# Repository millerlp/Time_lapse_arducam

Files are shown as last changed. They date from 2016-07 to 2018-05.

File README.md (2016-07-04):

# Timelapse_ArduCam

This repository contains Arduino code and Eagle design files for a circuit board to interface
with an ArduCam camera module to generate timelapse images. The device will sleep until a 
user defined interval (some number of seconds) is reached, then it will boot up the 
ArduCam module, take one picture, and write it to the SD card before returning to sleep. The
ArduCam module consumes > 100mA while idling, so the AVR microcontroller uses a transistor to
cut off all power to the ArduCam, and puts itself to sleep as well. During sleep intervals the
average overall current draw of the entire device is < 1mA. During an image capture and save 
routine (approx 5-6 seconds), power draw is around 130mA. 

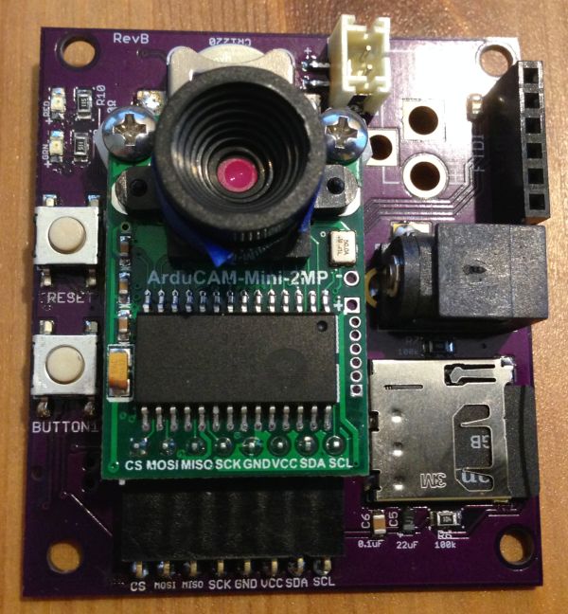
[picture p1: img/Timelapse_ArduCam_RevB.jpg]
Image of circuit board


The price for parts and the PCB boards should come out to $75, including the $30 cost of 
of the ArduCam OV2640 2 megapixel camera module
[Amazon link to camera module,](https://www.amazon.com/Arducam-Module-Megapixels-Arduino-Mega2560/dp/B012UXNDOY)
(note that the 5 megapixel version ought to work on this board as well) and the $22 cost to get 3 copies of the circuit board made by OshPark.com
[direct link to this board on Osh Park](https://oshpark.com/shared_projects/j0asS2vJ)

Features:
* Images are stored on a micro SD card.
* Timekeeping is accomplished with a DS3231 real time clock chip and backup battery.
* Power is provided by batteries through one of the available power plugs, either a 2.1mm barrel
connector or JST PH series plug (similar to that used on many Lithium battery packs). A 3.3V 
low dropout voltage regulator is included. I typically use 4 AA batteries to power the unit.
* A reset button and a trigger button are included, and can be mounted on either top or bottom 
of the board. 
* Indicator LEDs may also be mounted on the top or bottom of the board. 
* A FTDI header allows reprogramming of the AVR atmega328P microcontroller.
* A standard ICSP 2x3 header is available for burning a bootloader to the AVR. Alternatively, 
a Tag-Connect TC2030 footprint is available for ICSP functions as well. 

Necessary libraries:
* Arducam: https://github.com/ArduCAM/Arduino
* SdFat: https://github.com/greiman/SdFat
* RTClib: https://github.com/millerlp/RTClib

Written under Arduino 1.6.6

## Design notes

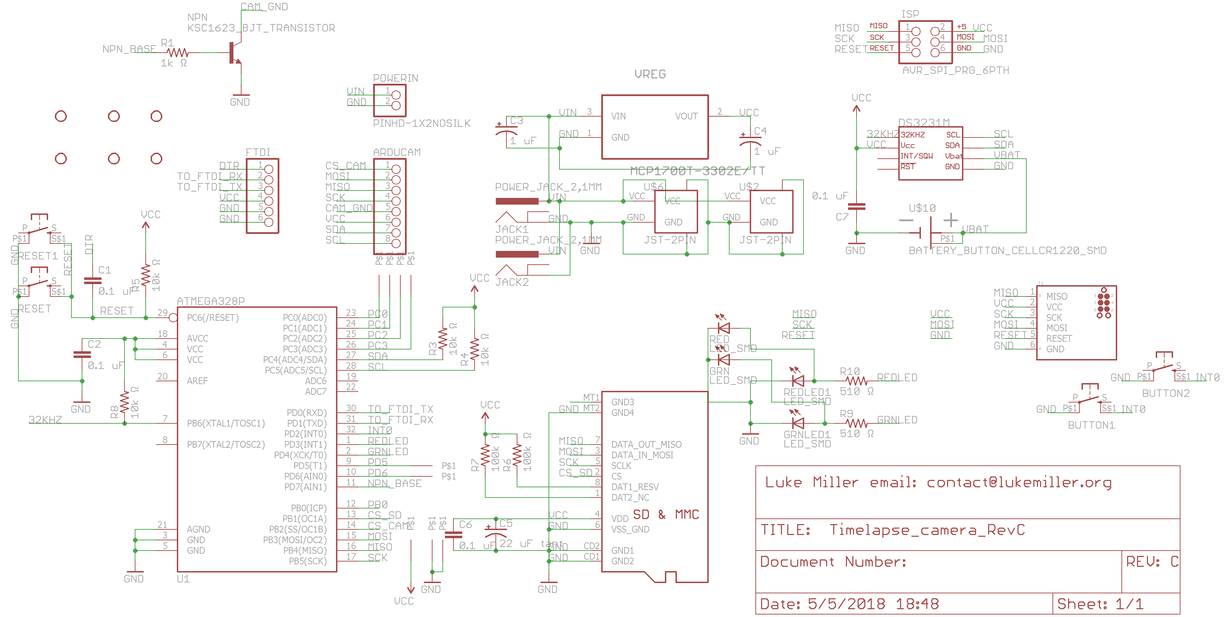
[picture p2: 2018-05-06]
Eagle_files/RevC/Timelapse_camera_RevC_schematic.png

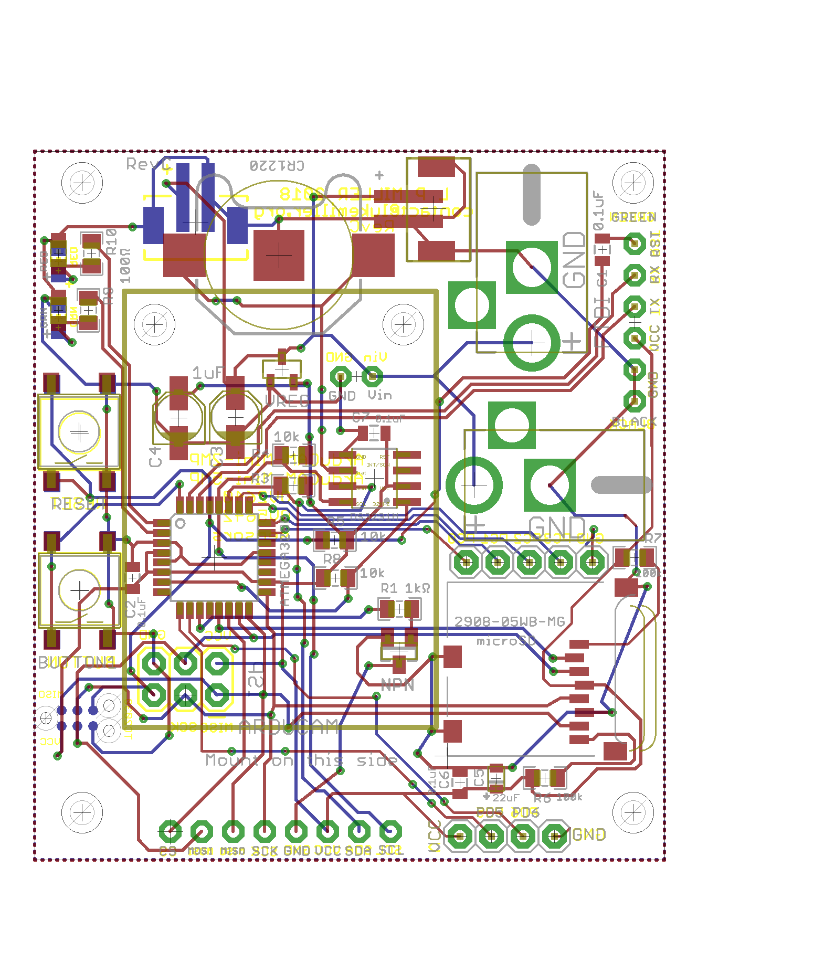
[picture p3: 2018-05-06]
Eagle_files/RevC/Timelapse_camera_RevC_board.png

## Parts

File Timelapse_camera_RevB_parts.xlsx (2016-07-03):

Part | Value | Package | Description | Manufacturer | Mfr. PN | Digikey PN | Price
ARDUCAM | ArduCam-Mini-2MP |  |  | ArduCam | ArduCam-Mini-2MP |  | $28.99
1x8 right angle female | PINHD-1X8RIGHTANGLE_FEMALE | 1X08-RA |  | Sullins Connector Solutions | PPPC081LGBN-RC | S5483-ND | $0.94
BUTTON1 |  | PUSHBUTTON_DPST_SMD | PUSHBUTTON DPST SMD | Omron | B3S-1000P | SW836CT-ND | $0.86
RESET |  | PUSHBUTTON_DPST_SMD | PUSHBUTTON DPST SMD |  | B3S-1000P | SW836CT-ND | $0.86
C2 | 0.1 uF ceramic 0805 | 805 | Capacitor | Taiyo Yuden | LMK212SD104KG-T | 587-1134-1-ND | $0.36
C3 | 1 uF electrolytic | PANASONIC_B | POLARIZED CAPACITOR, American symbol | Panasonic | EEE-FC1V1R0R | PCE4024CT-ND | $0.46
C4 | 1 uF electrolytic | PANASONIC_B | POLARIZED CAPACITOR, American symbol | Panasonic | EEE-FC1V1R0R | PCE4024CT-ND | $0.46
C5 | 22 uF tantalum 0805 | C0805_POL | POLARIZED CAPACITOR, American symbol | AVX Corp | F920J226MPA | 478-8119-1-ND | $0.49
C6 | 0.1 uF ceramic 0805 | 805 | Capacitor | Taiyo Yuden | LMK212SD104KG-T | 587-1134-1-ND | $0.36
C7 | 0.1 uF ceramic 0805 | 805 | Capacitor | Taiyo Yuden | LMK212SD104KG-T | 587-1134-1-ND | $0.36
DS3231M | DS3231MSOIC-8 | DS3231M_SOIC8 | DS3231M real time clock | Maxim | DS3231MZ/V+ | DS3231MZ/V+-ND | $6.46
FTDI | PINHD-1X6CB | 1X06-CLEANBIG | PIN HEADER | Sullins Connector Solutions | PPTC061LFBN-RC | S7004-ND | $0.68
GRN | LED_SMD 0805 | CHIPLED_0805 | LED surface mount 0805 | Lite-On | LTST-C171GKT | 160-1423-1-ND | $0.30
RED | LED_SMD 0805 | CHIPLED_0805 | LED surface mount 0805 | Lite-On | LTST-C171KRKT | 160-1427-1-ND | $0.32
NPN | KSC1623_BJT_TRANSISTOR | SOT23 | KSC1623 BJT NPN transistor - Fairchild Seminconductor KSC1623LMTF | Fairchild | KSC1623LMTF | KSC1623LMTFCT-ND | $0.20
R1 | 1k ohm 0805 | R0805 | RESISTOR, American symbol | Panasonic | ERJ-6GEYJ102V | P1.0KACT-ND (http://www.digikey.com/product-detail/en/ERJ-6GEYJ102V/P1.0KACT-ND/42833) | $0.10
R3 | 10k ohm 0805 | R0805 | RESISTOR, American symbol | Panasonic | ERJ-6GEYJ511V | P10KACT-ND (http://www.digikey.com/product-detail/en/ERJ-6GEYJ103V/P10KACT-ND/43118) | $0.10
R4 | 10k ohm 0805 | R0805 | RESISTOR, American symbol | Panasonic | ERJ-6GEYJ511V | P10KACT-ND (http://www.digikey.com/product-detail/en/ERJ-6GEYJ103V/P10KACT-ND/43118) | $0.10
R5 | 10k ohm 0805 | R0805 | RESISTOR, American symbol | Panasonic | ERJ-6GEYJ511V | P10KACT-ND (http://www.digikey.com/product-detail/en/ERJ-6GEYJ103V/P10KACT-ND/43118) | $0.10
R6 | 100k ohm 0805 | R0805 | RESISTOR, American symbol | Panasonic | ERJ-6GEYJ104V | P100KACT-ND (http://www.digikey.com/product-detail/en/ERJ-6GEYJ104V/P100KACT-ND/692) | $0.10
R7 | 100k ohm 0805 | R0805 | RESISTOR, American symbol | Panasonic | ERJ-6GEYJ104V | P100KACT-ND (http://www.digikey.com/product-detail/en/ERJ-6GEYJ104V/P100KACT-ND/692) | $0.10
R8 | 10k ohm 0805 | R0805 | RESISTOR, American symbol | Panasonic | ERJ-6GEYJ511V | P10KACT-ND (http://www.digikey.com/product-detail/en/ERJ-6GEYJ103V/P10KACT-ND/43118) | $0.10
R9 | 100 ohm 0805 | R0805 | RESISTOR, American symbol | Panasonic | ERJ-6GEYJ103V | P10KACT-ND | $0.10
R10 | 100 ohm 0805 | R0805 | RESISTOR, American symbol | Panasonic | ERJ-6GEYJ103V | P10KACT-ND | $0.10
JACK1 | POWER_JACK_2,1MM | POWER_JACK_DC_2,1MM | DC Power Jack, 2.1mm center pin. | CUI Inc | PJ-202AH | CP-202AH-ND | $1.16
U$2 | JST-2PIN | JST-2-SMD-VERT | JST B2B-PH-SM4-TM 2-pin connector |  | B2B-PH-K-S(LF)(SN) | 455-1704-ND | $0.17
U$3 | MICROSD | MICROSD | Micro-SD / Transflash card holder with SPI pinout | 3M | 2908-05WB-MG | 3M5607CT-ND | $3.60
U$10 | BATTERY_BUTTON_CELLCR1220_SMD | CR1220_BATTERY_HOLDER_SMD | Coin cell battery holders |  | 3000TR | 3000KCT-ND | $0.86
U1 | ATMEGA328P | TQFP32-08 | 32-Pin Atmega328 |  | ATMEGA328P-AU | ATMEGA328P-AU-ND | $3.58
VREG | MCP1700T-3302E/TT | SOT95P237X112-3N | Low Quiescent Current LDO | Microchip | MCP1700T-3302E/TT | MCP1700T3302ETTCT-ND | $0.37

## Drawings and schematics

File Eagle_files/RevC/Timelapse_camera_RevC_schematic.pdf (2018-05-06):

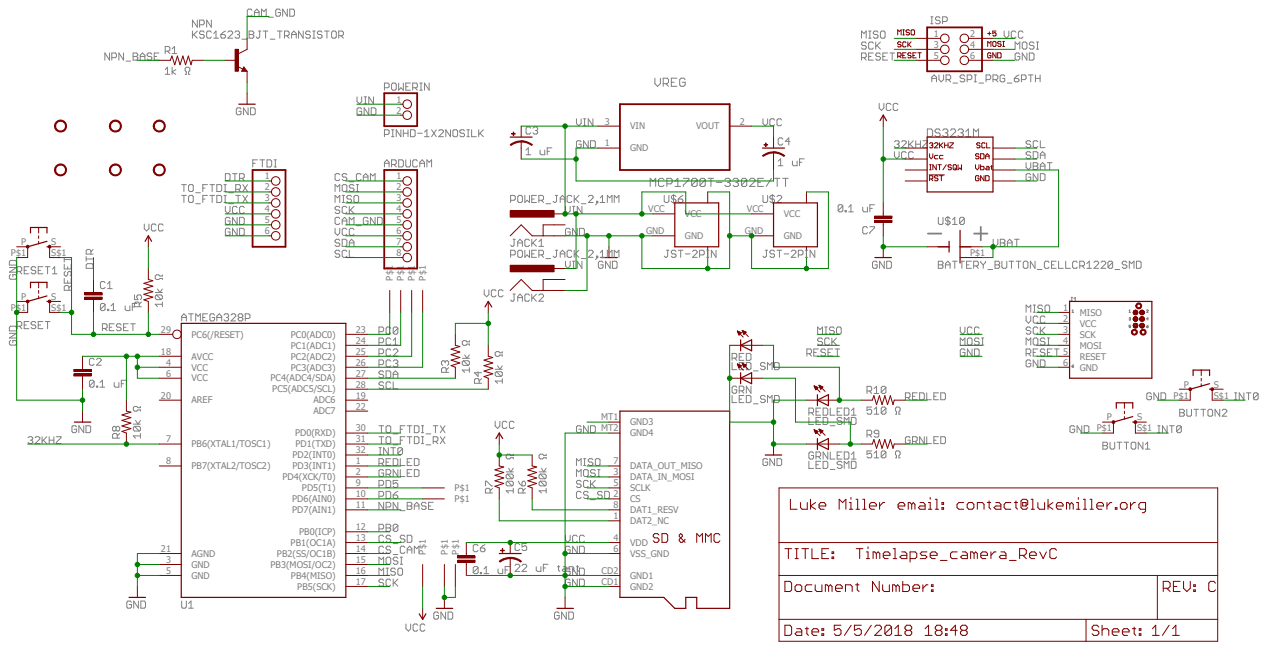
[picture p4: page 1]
PB5(SCK); 17 PB7(XTAL2/TOSC2) 8; PB6(XTAL1/TOSC1) 7; GND 3; GND 5; VCC 4; VCC 6; AGND 21; AREF 20; AVCC 18; PB4(MISO); 16 PB3(MOSI/OC2); 13 PB0(ICP); 12 PD7(AIN1); 11 PD6(AIN0); 9 PD4(XCK/T0); 2 PD3(INT1); 1 PD2(INT0); 32 PD1(TXD); 31 PD0(RXD); 30 ADC7; 22 ADC6; 19 PC5(ADC5/SCL); 28 PC4(ADC4/SDA); 27 PC3(ADC3); 26 PC2(ADC2); 25 PC1(ADC1); 24 PC0(ADC0); 23 PC6(/RESET) 29; VIN 3; GND 1; VOUT; DATA_IN_MOSI 3; VSS_GND 6; VDD 4; SCLK 5; DATA_OUT_MISO 7; DAT1_RESV 8; DAT2_NC 1; GND3 MT1; GND2 CD1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

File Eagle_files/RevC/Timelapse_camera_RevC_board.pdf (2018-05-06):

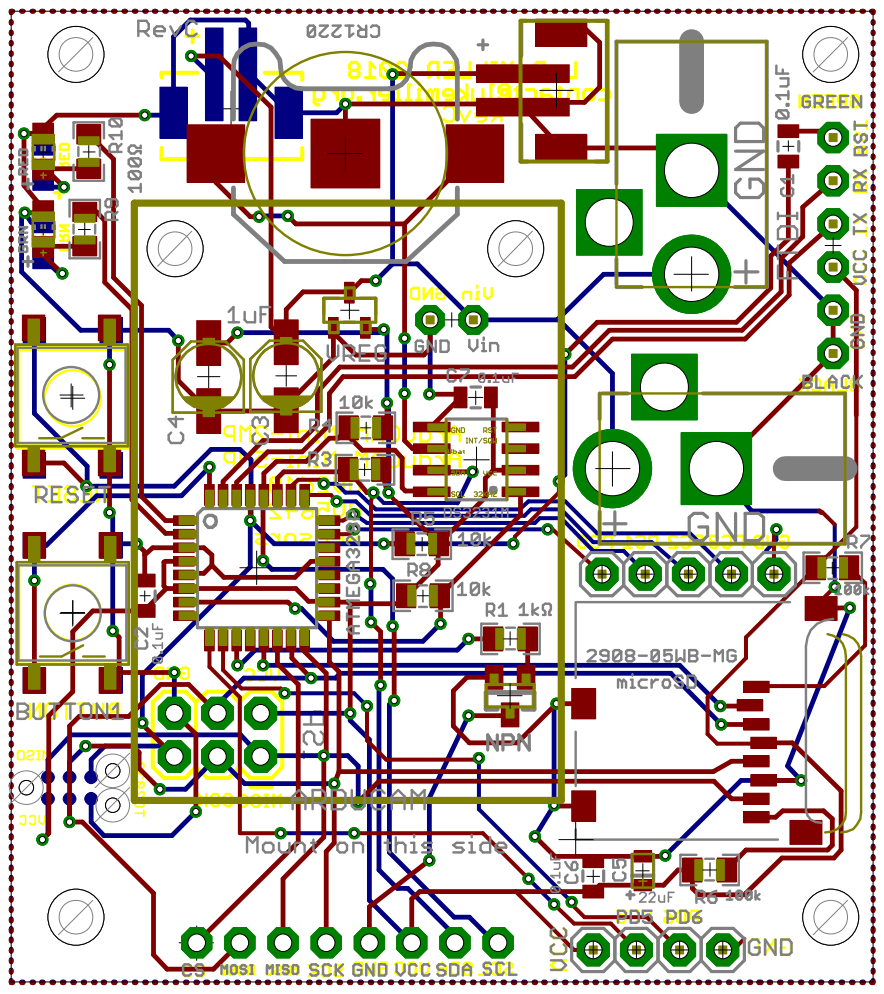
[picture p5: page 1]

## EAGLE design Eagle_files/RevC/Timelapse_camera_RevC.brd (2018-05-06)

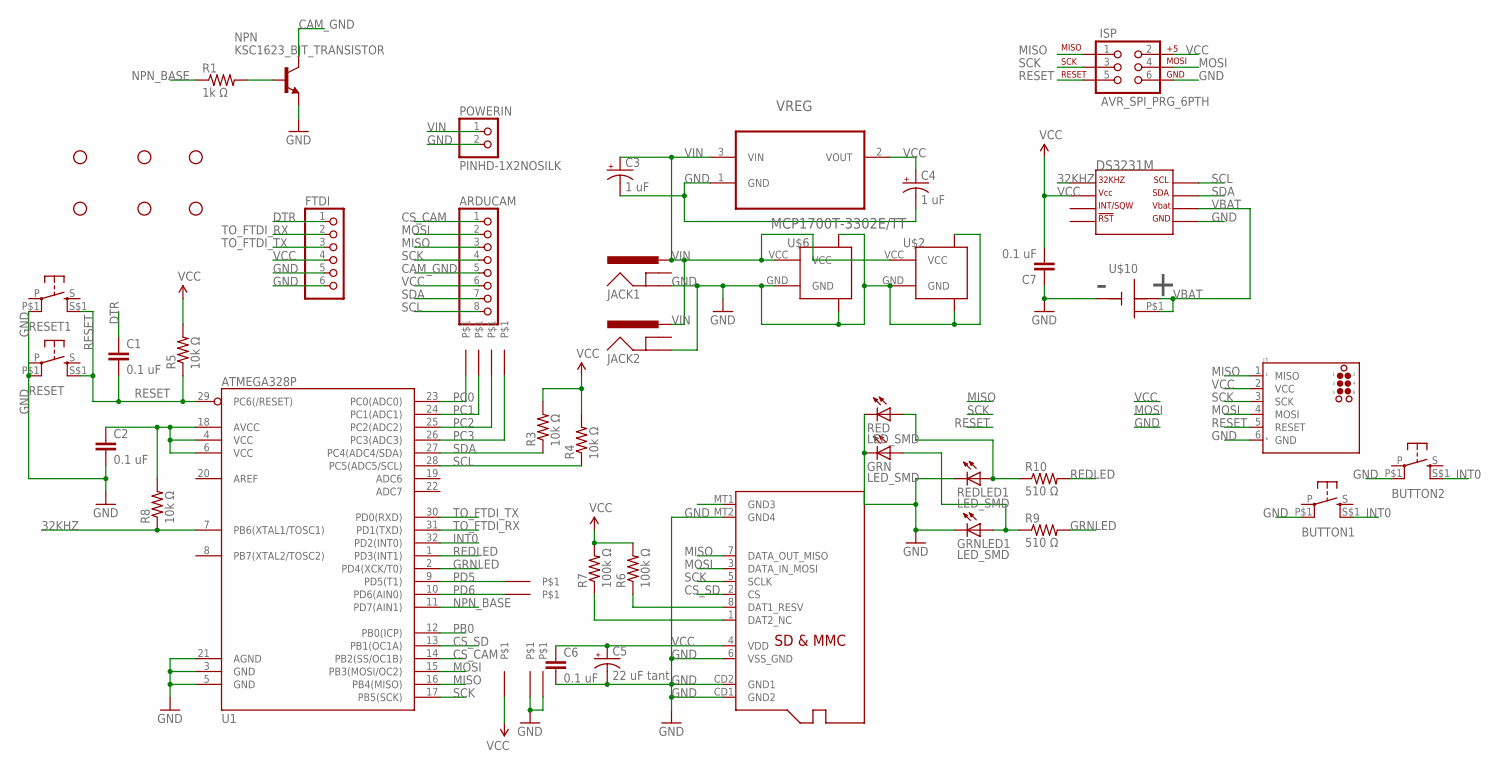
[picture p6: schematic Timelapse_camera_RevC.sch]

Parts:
ARDUCAM: PINHD-1X8RIGHTANGLE_FEMALE; 1X08-RA
BUTTON1, BUTTON2: PUSHBUTTON_DPST_SMDSTANDARD; PUSHBUTTON_DPST_SMD
C1, C2, C6, C7: 0.1 uF; 0805
C3, C4: 1 uF; PANASONIC_B
C5: 22 uF tant; C0805_POL
DS3231M: DS3231MSOIC-8; DS3231M_SOIC8
FTDI: PINHD-1X6CB; 1X06-CLEANBIG
GRN: LED_SMD; CHIPLED_0805
GRNLED1: LED_SMD; CHIPLED_0805
ISP: AVR_SPI_PRG_6PTH; 2X3
J1: TC2030-MCP-NL
JACK1, JACK2: POWER_JACK_2,1MM; POWER_JACK_DC_2,1MM
NPN: KSC1623_BJT_TRANSISTOR; SOT23
POWERIN: PINHD-1X2NOSILK; 1X02_NOSILK
R1: 1k Ω; R0805
R3, R4, R5, R8: 10k Ω; R0805
R6, R7: 100k Ω; R0805
R9, R10: 510 Ω; R0805
RED: LED_SMD; CHIPLED_0805
REDLED1: LED_SMD; CHIPLED_0805
RESET, RESET1: PUSHBUTTON_DPST_SMDSTANDARD; PUSHBUTTON_DPST_SMD
STANDOFF1, STANDOFF2, STANDOFF3, STANDOFF4, STANDOFF5, STANDOFF6: STAND-OFF
U1: ATMEGA328P; TQFP32-08
U$1, U$4, U$7, U$8, U$9, U$11, U$12, U$13, U$14: PINHD-1X1STANDARD; 1X01
U$2, U$6: JST-2PIN; JST-2-SMD-VERT
U$3: MICROSD
U$10: BATTERY_BUTTON_CELLCR1220_SMD; CR1220_BATTERY_HOLDER_SMD
VREG: MCP1700T-3302E/TT; SOT95P237X112-3N

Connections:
32KHZ: DS3231M.1 (P$1_32KHZ), R8.1, U1.7 (PB6(XTAL1/TOSC1))
CAM_GND: ARDUCAM.5, NPN.3 (C)
CD1: U$3.MT1 (GND3)
CS_CAM: ARDUCAM.1, U1.14 (PB2(SS/OC1B))
CS_SD: U1.13 (PB1(OC1A)), U$3.2 (CS)
DTR: C1.1, FTDI.1
GND: BUTTON1.P$1 (P1), BUTTON2.P$1 (P1), C2.2, C3.-, C4.-, C5.P$2_C (-), C6.2, C7.1, DS3231M.5 (P$5_GND), FTDI.5, FTDI.6, GRN.C, GRNLED1.C, ISP.6, J1.6 (GND), JACK1.P$2 (GND), JACK2.P$2 (GND), NPN.2 (E), POWERIN.2, RED.C, REDLED1.C, RESET.P$1 (P1), RESET1.P$1 (P1), U1.3 (GND), U1.5 (GND), U1.21 (AGND), U$2.GND, U$2.P$1 (BODY1), U$2.P$2 (BODY2), U$3.6 (VSS_GND), U$3.CD1 (GND2), U$3.CD2 (GND1), U$3.MT2 (GND4), U$6.GND, U$6.P$1 (BODY1), U$6.P$2 (BODY2), U$10.GND, U$12.1, U$14.1, VREG.1 (GND)
GRNLED: R9.2, U1.2 (PD4(XCK/T0))
INT0: BUTTON1.S$1 (S1), BUTTON2.S$1 (S1), U1.32 (PD2(INT0))
MISO: ARDUCAM.3, ISP.1, J1.1 (MISO), U1.16 (PB4(MISO)), U$3.7 (DATA_OUT_MISO)
MOSI: ARDUCAM.2, ISP.4, J1.4 (MOSI), U1.15 (PB3(MOSI/OC2)), U$3.3 (DATA_IN_MOSI)
unnamed: NPN.1 (B), R1.2
unnamed: R7.1, U$3.1 (DAT2_NC)
unnamed: R6.1, U$3.8 (DAT1_RESV)
unnamed: GRN.A, GRNLED1.A, R9.1
unnamed: R10.1, RED.A, REDLED1.A
NPN_BASE: R1.1, U1.11 (PD7(AIN1))
PB0: U1.12 (PB0(ICP))
PC0: U1.23 (PC0(ADC0)), U$1.1
PC1: U1.24 (PC1(ADC1)), U$4.1
PC2: U1.25 (PC2(ADC2)), U$7.1
PC3: U1.26 (PC3(ADC3)), U$8.1
PD5: U1.9 (PD5(T1)), U$9.1
PD6: U1.10 (PD6(AIN0)), U$11.1
REDLED: R10.2, U1.1 (PD3(INT1))
RESET: C1.2, ISP.5, J1.5 (RESET), R5.1, RESET.S$1 (S1), RESET1.S$1 (S1), U1.29 (PC6(/RESET))
SCK: ARDUCAM.4, ISP.3, J1.3 (SCK), U1.17 (PB5(SCK)), U$3.5 (SCLK)
SCL: ARDUCAM.8, DS3231M.8 (P$8_SCL), R4.1, U1.28 (PC5(ADC5/SCL))
SDA: ARDUCAM.7, DS3231M.7 (P$7_SDA), R3.1, U1.27 (PC4(ADC4/SDA))
TO_FTDI_RX: FTDI.2, U1.31 (PD1(TXD))
TO_FTDI_TX: FTDI.3, U1.30 (PD0(RXD))
VBAT: DS3231M.6 (P$6_VBAT), U$10.P$1 (P$2_VBAT), U$10.P$2 (VBAT)
VCC: ARDUCAM.6, C2.1, C4.+, C5.P$1_A (+), C6.1, C7.2, DS3231M.2 (P$2_VCC), FTDI.4, ISP.2, J1.2 (VCC), R3.2, R4.2, R5.2, R6.2, R7.2, R8.2, U1.4 (VCC), U1.6 (VCC), U1.18 (AVCC), U$3.4 (VDD), U$13.1, VREG.2 (VOUT)
VIN: C3.+, JACK1.P$1 (PWR), JACK2.P$1 (PWR), POWERIN.1, U$2.VCC, U$6.VCC, VREG.3 (VIN)

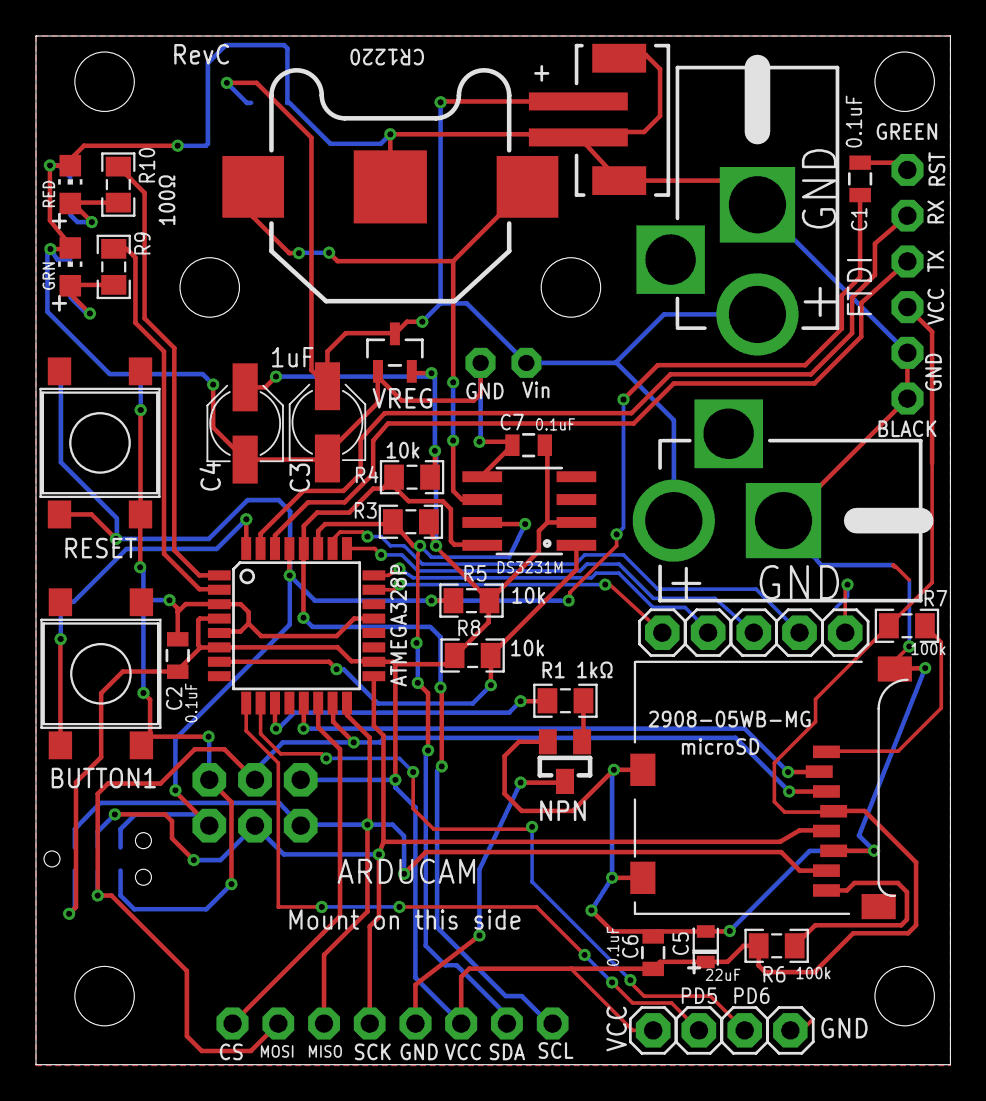
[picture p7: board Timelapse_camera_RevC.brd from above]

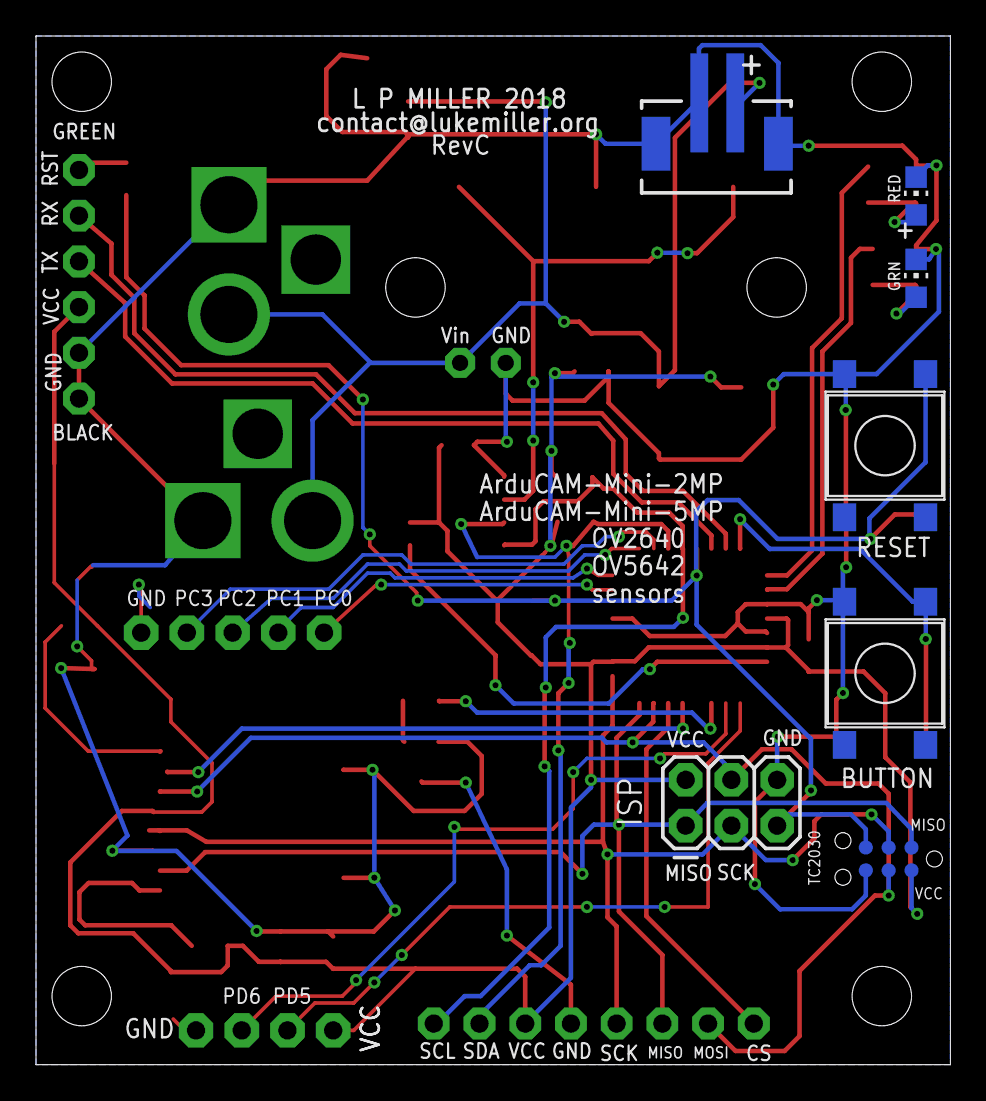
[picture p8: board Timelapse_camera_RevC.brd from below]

Board: 2 copper layers, 50.8 x 57.1 mm, 54 parts (8 on the bottom side), 32 nets.

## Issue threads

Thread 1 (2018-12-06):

Code does not compile?

jdwolin, 2018-12-06:
Great looking script.  I built your board but the code does not seem to compile?  Any thoughts on why this is having problems?  Perhaps a library has been updated?

/Users/Jason Wolin/Dropbox/My Hobbies/Timelapse/Timelapse.ino: In function 'void setup()':
C:/Users/Jason Wolin/Dropbox/My Hobbies/Timelapse/Timelapse.ino:291:10: error: 'class DateTime' has no member named 'toString'
pinMode(SCL, INPUT);  // Disable I2C again
^
C:/Users/Jason Wolin/Dropbox/My Hobbies/Timelapse/Timelapse.ino:337:24: error: 'FIFO_PWRDN_MASK' was not declared in this scope
digitalWrite(REDLED, HIGH); // turn on error LED
^
C:/Users/Jason Wolin/Dropbox/My Hobbies/Timelapse/Timelapse.ino:339:24: error: 'LOW_POWER_MODE' was not declared in this scope
// Transfer data from ArduCam to the SD card
^
C:/Users/Jason Wolin/Dropbox/My Hobbies/Timelapse/Timelapse.ino: In function 'void loop()':
C:/Users/Jason Wolin/Dropbox/My Hobbies/Timelapse/Timelapse.ino:571:9: error: 'class DateTime' has no member named 'toString'
start_capture = 0;
^
C:\Users\Jason Wolin\.platformio\lib\RTClib\RTClib.cpp: In constructor 'DateTime::DateTime(uint32_t)':
C:\Users\Jason Wolin\.platformio\lib\RTClib\RTClib.cpp:86:18: warning: comparison between signed and unsigned integer expressions [-Wsign-compare]
if (days < 365 + leap)
^
C:/Users/Jason Wolin/Dropbox/My Hobbies/Timelapse/Timelapse.ino: In function 'void enableArduCam()':
C:/Users/Jason Wolin/Dropbox/My Hobbies/Timelapse/Timelapse.ino:1003:25: error: 'LOW_POWER_MODE' was not declared in this scope
C:/Users/Jason Wolin/Dropbox/My Hobbies/Timelapse/Timelapse.ino: In function 'DateTime startTIMER2(DateTime)':
C:/Users/Jason Wolin/Dropbox/My Hobbies/Timelapse/Timelapse.ino:1321:7: error: 'class RTC_DS3231' has no member named 'enable32kHz'
*** [.pioenvs\nanoatmega328\src\Timelapse.ino.cpp.o] Error 1
 [ERROR] Took 12.70 seconds

millerlp, 2018-12-06:
Some of those errors look like the result of using the wrong RTClib library. Are you using the version from my repository: https://github.com/millerlp/RTClib ?

jdwolin, 2018-12-07:
Yes, that was it!  Perfect.  Thank you for your help.

Closed 2018-12-07.

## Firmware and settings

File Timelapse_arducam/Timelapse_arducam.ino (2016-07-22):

/* Timelapse_arducam.ino
 *  LPM 2016
 *  
 *  LED status codes:
 *  Reboot: 1 green flash for 1 second, followed by two sets of
 *    quick green flashes (5 each) to denote that the camera and
 *    SD card both passed initialization tests. 
 *  Green 2 quick flashes, then 1 quick flash ~3-7 seconds later:   
 *    camera waking, taking picture, and finishing write to SD card
 *  Press Button1, get 2 quick red flashes, then 1 red flash ~ 3-7    
 *    seconds later: manual picture taken.     
 *  LED error codes:  
 *  Red + Green alternating slowly (1 second): real time clock
 *    is not set properly
 *  Red + Green alternating more quickly (1/2 second): camera
 *    module does not return expected ID.
 *  Red + Green alternating quickly ( 1/10 second): SD card not  
 *    initializing properly
 *  
 *  Made for RevB of Timelapse Arducam board
 *  RevB contains a NPN transistor to shut down the
 *  Arducam module. 
 *  Time is provided by a DS3231M RTC chip. 
 *  
 *  Uses roughly 140mA when camera is on, but drops to <1mA when 
 *  camera is completely shut down between picture taking events.
 *  
 *  Change the variable Interval to specify what seconds value 
 *  (of each minute) to take a picture on.
 *  For example: Use Interval = 10 to take 6 pictures per minute,
 *                  on the 0,10,20,30,40,50-second marks
 *               Use Interval = 15 to take 4 pictures per minute
 *                  on the 0, 15, 30, 45 second marks
 *               Use Interval = 30 to take 2 pictures per minute
 *                  on the 0 and 30 second marks
 *  The actual timestamp for the image capture will be later,                 
 *  based on the value entered for cameraWarmUpTime (see below).
 *                  
 *  Change the variable dawnTime and duskTime to specify times of                
 *    day when the camera should take pictures. For instance, if
 *    you start seeing daylight around 5AM, set dawnTime = 5
 *    If you get darkness by 9PM, set duskTime = 21. If it is 
 *    earlier than 5AM or later than 9PM, the camera will not
 *    take any pictures, and will conserve battery power. 
 *    For constant running, set dawnTime = 0 and duskTime = 24
 *    
 *  Change cameraWarmUpTime to specify the amount of milliseconds  
 *    that the program should wait while the camera is first 
 *    powering up and doing its autoexposure routine. A good
 *    choice is cameraWarmUpTime = 3000  (= 3 seconds). Shorter
 *    warm up times will result in dark pictures, bad color 
 *    balance, or severely blown out highlights. Longer warm up
 *    times beyond 3000ms may not improve the image noticeably.
 *    Longer warm up times will use more battery power. 
 *    
 *  NOTE - when first installing the ArduCAM library,
 *  you will need to open the memorysaver.h file and
 *  uncomment the #define line that matches your
 *  particular sensor. The default is the OV2640_CAM. 
 */ 


#include <SdFat.h>  // https://github.com/greiman/SdFat
#include <Wire.h>
#include "ArduCAM.h"  // https://github.com/ArduCAM/Arduino
#include <SPI.h>
#include "memorysaver.h"  // https://github.com/ArduCAM/Arduino
#include "RTClib.h"   // https://github.com/millerlp/RTClib


// The following libraries should come with the normal Arduino 
// distribution. 
#include <avr/interrupt.h>
#include <avr/sleep.h>
#include <util/atomic.h>
#include <wiring_private.h>
#include <avr/wdt.h>

// Define the CS pin for the SD card 
#define SD_CS 9    // arduino pin 9, avr pin PB1
#define SPI_CS 10  // Arducam CS, arduino pin 10, avr pin PB2
#define REDLED 3  // Red LED
#define GRNLED 4  // Green LED
#define BUTTON1 2   // Tactile switch (INT0)
#define NPN 7 // Base pin of NPN transistor

// Define the sleep/wake cycle (seconds)
// This is NOT the picture-taking interval, so don't change it
#define SAMPLES_PER_SECOND 1

//-------------------------------------------
// User-settable variables
int dawnTime = 5;  // Specify hour before which no pictures should be taken
int duskTime = 21;  // Specify hour after which no pictures should be taken
int Interval = 30; // Specify a seconds mark to take picture on (10, 15, 20, 30)
                  // A normal picture+save operation takes ~ 5-8 seconds
int cameraWarmUpTime = 3000; // (ms) Delay to let camera stabilize after waking
//-------------------------------------------


// Create SD card objects
SdFat sd;
SdFile outFile;  // for sd card, this is the file object to be written to

// Create real time clock object
RTC_DS3231 rtc; 
DateTime myTime;  // variable to keep time

// ArduCam variables
ArduCAM myCAM(OV2640,SPI_CS); // Defines camera module type and chip select pin
uint8_t start_capture = 0;
int total_time = 0;

// Declare initial name for output files written to SD card
// The newer versions of SdFat library support long filenames
char filename[] = "YYYYMMDD_HHMMSS.JPG";

//**************************************
void setup()
{
  pinMode(GRNLED, OUTPUT);
  pinMode(REDLED, OUTPUT);
  pinMode(SPI_CS, OUTPUT);
  pinMode(NPN, OUTPUT);
  digitalWrite(NPN, HIGH); // HIGH turns on Arducam
  
  // Define a trigger pin (connect to ground to trigger)
  pinMode(BUTTON1, INPUT_PULLUP);
  
  uint8_t vid,pid;
  uint8_t temp; 

  // Flash Green LED to show reboot happened
  digitalWrite(GRNLED, HIGH);
  delay(1000);
  digitalWrite(GRNLED, LOW);
  delay(500);


  Serial.begin(57600);
  Serial.println(F("Reboot"));
  
  rtc.begin();
  myTime = rtc.now();
  char buf1[25];
  myTime.toString(buf1, 25);
  Serial.println(buf1);
  // Check the year to see if it's sensible. If not, 
  // notify the user by flashing the red LED a bunch.
   if ( (myTime.year() < 2016) | (myTime.year() >= 2164) ){
      for (int j = 0; j < 30; j++){ 
          digitalWrite(REDLED, HIGH);
          delay(1000);
          digitalWrite(REDLED, LOW);
          delay(1000);
          Serial.println(F("RTC error"));
      }
   }

  // initialize SPI:
  SPI.begin(); 
  
  //***********************************
  // Initialize Arducam module
  // Clear the power down bit in case the device
  // was left in power-down mode (re-enables ArduCAM module)
  myCAM.clear_bit(ARDUCHIP_GPIO,GPIO_PWDN_MASK);  // SPI bus
  // Re-enable the memory controller circuit
	myCAM.clear_bit(0x83, FIFO_PWRDN_MASK); // SPI bus
	myCAM.clear_bit(0x83, LOW_POWER_MODE);    // SPI bus
  //Check if the ArduCAM SPI bus is OK
  myCAM.write_reg(ARDUCHIP_TEST1, 0x55);  // SPI bus
  temp = myCAM.read_reg(ARDUCHIP_TEST1);  // SPI bus
  // Check if the ArduCAM SPI bus is OK
  myCAM.write_reg(ARDUCHIP_TEST1, 0x55);
  temp = myCAM.read_reg(ARDUCHIP_TEST1);
  if(temp != 0x55)
  {
    Serial.println("SPI interface Error!");
    digitalWrite(REDLED, HIGH);
    while(1); // Hang here, since a missing camera is useless
  } 
  
  // Change MCU mode
  // MCU2LCD_MODE denotes that microcontroller is responsible
  // for interfacing with a LCD display screen, rather than 
  // the ArduCAM chip
  myCAM.set_mode(MCU2LCD_MODE); // SPI bus

  // For interfacing with a LCD display screen (or SD card), 
  // rather than the ArduCAM chip
  myCAM.set_mode(MCU2LCD_MODE);
  
  // Check if the camera module type is OV2640
  myCAM.rdSensorReg8_8(OV2640_CHIPID_HIGH, &vid);
  myCAM.rdSensorReg8_8(OV2640_CHIPID_LOW, &pid);
  if ( (vid != 0x26) || (pid != 0x42) ) {
    Serial.println(F("Can't find OV2640 module!"));
    while(1){ // infinite loop due to module initialization error
            
            digitalWrite(REDLED, HIGH);
            delay(500);
            digitalWrite(REDLED, LOW);
            digitalWrite(GRNLED, HIGH);
            delay(500);
            digitalWrite(GRNLED, LOW);
    	  }
  } else {
    Serial.println(F("OV2640 detected"));

    // Give 5 quick flashes to denote that the 
    // camera was successfully detected
    for (int j = 0; j < 5; j++){
      digitalWrite(GRNLED,HIGH);
      delay(50);
      digitalWrite(GRNLED,LOW);
      delay(50);
    }
  }
  delay(500);
    
  //Change to JPG capture mode and initialize the OV2640 module     
  myCAM.set_format(JPEG);

  myCAM.InitCAM();
  
  // Set the camera module power down bit (enters power down mode)
  myCAM.set_bit(ARDUCHIP_GPIO,GPIO_PWDN_MASK);
  
  //**************************************
	// Initialize the SD card object
	// Try SPI_FULL_SPEED, or SPI_HALF_SPEED if full speed produces
	// errors on a breadboard setup. 
  if (!sd.begin(SD_CS, SPI_FULL_SPEED)) {
  	// If the above statement returns FALSE after trying to 
  	// initialize the card, enter into this section and
  	// hold in an infinite loop.
    Serial.println(F("SD card error"));
    while(1){ // infinite loop due to SD card initialization error
            digitalWrite(REDLED, HIGH);
            delay(100);
            digitalWrite(REDLED, LOW);
            digitalWrite(GRNLED, HIGH);
            delay(100);
            digitalWrite(GRNLED, LOW);
    	  }
  } else {
		Serial.println(F("SD init"));
   // Give a quick set of flashes to denote
   // that the SD card was initialized
    for (int j = 0; j < 5; j++){
      digitalWrite(GRNLED,HIGH);
      delay(50);
      digitalWrite(GRNLED,LOW);
      delay(50);
    }
  }

  //*******************************************
  // Power down the ArduCAM module and set all of its
  // pins to inputs in order to stop any parasitic power
  // draw
  SPI.end();
  digitalWrite(13, LOW);
  pinMode(13, INPUT);   // SPI SCK
  pinMode(12, INPUT);   // SPI MISO   
  pinMode(11, INPUT);   // SPI MOSI
  pinMode(10, INPUT);   // SPI Chip select for Arducam
  // Shut down I2C (Wire) functions temporarily
  pinMode(SDA, INPUT);  // I2C SDA line
  pinMode(SCL, INPUT);  // I2C SCL line
  digitalWrite(NPN, LOW); // disconnect Arducam's ground pin
  
  startTIMER2(myTime);
    
} // end of setup() loop
//*************************************************

//*************************************************
void loop()
{
	// Check time at start of every loop
  Wire.begin();
	myTime = rtc.now();
	char buf1[25];
	myTime.toString(buf1, 25);
	Serial.println(buf1);
	delay(5);
  // Shut down I2C (Wire) functions temporarily
  pinMode(SDA, INPUT);  // Disable I2C again
  pinMode(SCL, INPUT);  // Disable I2C again

  // Only take pictures during specified hours
  if ( (myTime.hour() >= dawnTime) & (myTime.hour() <= duskTime) ) {
    // Take a picture every Interval seconds
    if (myTime.second() % Interval == 0){
      total_time = millis(); // store time used to take and store picture 
      // Call enableArduCam function to turn the module back on
      enableArduCam();
      start_capture = 1;
      // Flush the FIFO 
      myCAM.flush_fifo(); 
      // Clear the capture done flag before starting new capture
      myCAM.clear_fifo_flag();   

      // Flash green LED 2 times quickly to denote start of picture
      // capture
      for (int j = 0; j < 2; j++){
        digitalWrite(GRNLED, HIGH);
        delay(50);
        digitalWrite(GRNLED, LOW);
        delay(50);
      }
      delay(cameraWarmUpTime); // Let camera exposure stabilize before picture
      
      // Start capture
      myCAM.start_capture();    
      // Check the Capture Done flag, which is stored in the ARDUCHIP_TRIG
      // register for some reason.
      while (!myCAM.get_bit(ARDUCHIP_TRIG, CAP_DONE_MASK)) {
        // do nothing while waiting for capture done flag
      }
  
      if ( myCAM.get_bit(ARDUCHIP_TRIG, CAP_DONE_MASK) ) {
         Serial.println(F("Capture Done"));
    
        // Update the time stamp. This will be the actual time
        // value of the image capture (after the warm up), and 
        // will be used in the image file name.
         myTime = rtc.now();
        // Construct a file name
        initFileName(myTime);
        // Open a new file on the SD card with the filename
        if (!outFile.open(filename, O_RDWR | O_CREAT | O_AT_END)) {
          // If file cannot be created, raise an error
          Serial.println(F("SD card error"));
          digitalWrite(REDLED, HIGH); // turn on error LED
        }
        // Transfer data from ArduCam to the SD card
        writeToSD(myTime);
        
        total_time = millis() - total_time;
        Serial.print(F("Total time used:"));
        Serial.print(total_time, DEC);
        Serial.println(F(" ms")); 

        // Flash green LED again to denote the end of the 
        // image capture cycle. 
        digitalWrite(GRNLED,HIGH);
        delay(15); // Give Serial time to write   
        digitalWrite(GRNLED,LOW);

        // Power down the ArduCam (this disables I2C and SPI also)
        disableArduCam();
      } // end of if(myCAM.get_bit(ARDUCHIP_TRIG ,CAP_DONE_MASK))
    } // end of if (myTime.second() % 30 == 0)
  } // end of if (myTime.hour() >= dawnTime & myTime.hour() <= duskTime) 
  // At this point a picture has been take and stored if the code above
  // executed.
  //--------------------------------------------------------------------
  // Alternatively, recognize a button trigger push, and take a picture
  // manually. A low signal on BUTTON1 means the button is currently 
  // being triggered.
  if ( digitalRead(BUTTON1) == 0)  
  {
    Serial.println(F("Trigger"));
    digitalWrite(REDLED, HIGH);
    delay(40);
    digitalWrite(REDLED, LOW);

    total_time = millis(); // Store time used to take and store picture 
    // Call enableArduCam function to turn the module back on
    enableArduCam();
      
    // Wait until button is released
  	digitalWrite(REDLED, HIGH);
      while(digitalRead(BUTTON1) == 0);  
      delay(10);
  	digitalWrite(REDLED, LOW);
      start_capture = 1;
  }

  if (start_capture)
  {
    // Flush the FIFO 
    myCAM.flush_fifo();   // SPI bus
    // Clear the capture done flag before starting new capture
    myCAM.clear_fifo_flag();   
    
    delay(cameraWarmUpTime); // Let camera exposure stabilize before picture
    
    // Start capture
    myCAM.start_capture();    
	  // Check the Capture Done flag, which is stored in the ARDUCHIP_TRIG
	  // register for some reason.
	while (!myCAM.get_bit(ARDUCHIP_TRIG, CAP_DONE_MASK)) {
	  // do nothing while waiting for capture done flag
	}
	
	if (myCAM.get_bit(ARDUCHIP_TRIG ,CAP_DONE_MASK)) {
		 Serial.println(F("Capture Done"));

    // Update the time stamp
     myTime = rtc.now();
		// Construct a file name
		initFileName(myTime);
		// Open a new file on the SD card with the filename
		if (!outFile.open(filename, O_RDWR | O_CREAT | O_AT_END)) {
			// If file cannot be created, raise an error
			Serial.println(F("SD card error"));
			digitalWrite(REDLED, HIGH); // turn on error LED
		}
    // Transfer data from ArduCam to the SD card
    writeToSD(myTime);
		
		total_time = millis() - total_time;
		Serial.print(F("Total time used:"));
		Serial.print(total_time, DEC);
		Serial.println(F(" ms"));
    delay(5); // Give Serial time to write    

    // Power down the ArduCam (this disables I2C and SPI also)
    disableArduCam();
   
		digitalWrite(REDLED, HIGH);
		delay(800);
		digitalWrite(REDLED, LOW);

	  }
  } // End of manual trigger mode
  
	// Put the AVR to sleep
	goToSleep();
	
} // end of main loop()
//--------------------------------------------------------------------

// Function definitions

//-----------------------------------------------------------------------------
// This Interrupt Service Routine (ISR) is called every time the
// TIMER2_OVF_vect goes high (==1), which happens when TIMER2
// overflows. The ISR doesn't care if the AVR is awake or
// in SLEEP_MODE_PWR_SAVE, it will still roll over and run this
// routine. If the AVR is in SLEEP_MODE_PWR_SAVE, the TIMER2
// interrupt will also reawaken it. This is used for the goToSleep() function
ISR(TIMER2_OVF_vect) {
}

//------------enableArduCam--------------------------------------------------
// A function to wake and intialize the ArduCam. This is in a function
// just to make the code in the main loop more compact and readable
void enableArduCam (void) 
{
  uint8_t temp;
  Wire.begin();
  SPI.begin();
  digitalWrite(NPN, HIGH); // power up Arducam supply
  
  // Time to power stuff back up and take a picture
  
  // Initialize the SD card object
  // Try SPI_FULL_SPEED, or SPI_HALF_SPEED if full speed produces
  // errors on a breadboard setup. 
  pinMode(SD_CS, OUTPUT); 
  if (!sd.begin(SD_CS, SPI_FULL_SPEED)) {
  // If the above statement returns FALSE after trying to 
  // initialize the card, enter into this section and
  // hold in an infinite loop.
  Serial.println(F("SD card error"));
  while(1){ // infinite loop due to SD card initialization error
      
      digitalWrite(REDLED, HIGH);
      delay(100);
      digitalWrite(REDLED, LOW);
      digitalWrite(GRNLED, HIGH);
      delay(100);
      digitalWrite(GRNLED, LOW);
      }
  } else {
    Serial.println(F("SD init"));
  } 
  
  // Renable the ArduCAM module
  
  pinMode(SPI_CS, OUTPUT);

  // Check if the ArduCAM SPI bus is OK
  myCAM.write_reg(ARDUCHIP_TEST1, 0x55);
  temp = myCAM.read_reg(ARDUCHIP_TEST1);
  if(temp != 0x55)
  {
    Serial.println(F("SPI interface Error!"));
    while(1);
  } else {
    Serial.println(F("Arducam OK"));
  }
  
  // Re-enable the sensor module 
  myCAM.clear_bit(ARDUCHIP_GPIO, GPIO_PWDN_MASK);
  // Re-enable the memory controller circuit
  myCAM.clear_bit(0x83, LOW_POWER_MODE); 

  // Reset all of the sensor module settings
  myCAM.set_mode(MCU2LCD_MODE);
  myCAM.set_format(JPEG);
  myCAM.InitCAM();
  myCAM.OV2640_set_JPEG_size(OV2640_1600x1200);    
} // end of enableArduCam function
//-----------------------------------------------------------


//-------------writeToSD--------------------
// Function to transfer data from Arducam buffer to 
// a file on SD card
void writeToSD(DateTime myTime)
{
  byte buf[256]; // used for moving image data to SD card
  int i = 0; // used to keep track of image data saving
  uint8_t temp = 0; // used to hold each image byte
  uint8_t temp_last = 0; // used to hold previous image byte
  
  temp = myCAM.read_fifo(); // Get 1 byte from camera fifo buffer
  // Write first image data to buffer
  buf[i++] = temp;


  // Read JPEG data from FIFO
  // JPEGs should end with FF D9 (hex), so this
  // statement looks for that code to determine whether 
  // this is the end of the file or not. 
  while( (temp != 0xD9) | (temp_last != 0xFF) )
  {
    temp_last = temp;
    temp = myCAM.read_fifo(); // read another byte
      // Write image data to buffer if not full
    if (i < 256){
      buf[i++] = temp;
    } else {  // if i == 256, i.e. 'buf' is full
      // Write 256 bytes image data to file on SD card
      outFile.write(buf,256);
      i = 0;  // reset buf index to 0
      buf[i++] = temp; // copy the recent byte to the start of buf
    }
  }
  // Write the remaining bytes in the buffer since the
  // previous while statement has been satisfied now
  if (i > 0) {
    outFile.write(buf, i);
  }
  
  // Update the file's creation date, modify date, and access date.
  outFile.timestamp(T_CREATE, myTime.year(), myTime.month(), myTime.day(), 
      myTime.hour(), myTime.minute(), myTime.second());
  outFile.timestamp(T_WRITE, myTime.year(), myTime.month(), myTime.day(), 
      myTime.hour(), myTime.minute(), myTime.second());
  outFile.timestamp(T_ACCESS, myTime.year(), myTime.month(), myTime.day(), 
      myTime.hour(), myTime.minute(), myTime.second());
  // Close the file 
  outFile.close(); 
}   // End of writeToSD function
//-----------------------------------------------------------

//----------------disableArduCam----------------
// Function to shut ArduCam module down completely
void disableArduCam(void)
{
    // Clear the capture done flag 
    myCAM.clear_fifo_flag();
    // Clear the start capture flag
    start_capture = 0;
    
    // Shut down the SPI lines, turn outputs into INPUT to prevent
    // parasitic power loss
    SPI.end();
    digitalWrite(13, LOW);
    pinMode(13, INPUT);  
    pinMode(12, INPUT);
    pinMode(11, INPUT);
    pinMode(10, INPUT);
    pinMode(SDA, INPUT); // Disable I2C pins
    pinMode(SCL, INPUT); // Disable I2C pins
    // Kill the Arducam's power supply
    digitalWrite(NPN, LOW); 
    
}   // end of disableArduCam function
//----------------------------------------------------------
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

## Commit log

2016-06-15 Updating for RevA camera board hardware
2016-06-16 Functional on RevA hardware, but power hungry
2016-07-03 Enabling basic functionality with RevB hardware
    This works with the RevB board, but only proves that the thing takes a
    picture. No real low power sleeping happens.
2016-07-03 Semi-functional status, does not fully power down
    This will take pictures on command on RevB hardware, but turning off the
    power to the Arducam via the NPN transistor appears to kill the I2C
    communications as well, which is weird.
2016-07-03 All SPI/I2C pins as inputs, seems to still loop properly
    Need to see if the Arducam is truly being powered down though, or if
    it's still getting parasitic power from somewhere.
2016-07-03 Functional test, sleep mode power down works
    Camera current is dropping to < 1mA when the Arducam power is cut off.
    Pressing button1 wakes the camera and successfully takes a picture (at
    120-140mA current draw) for 3-4 seconds, then resumes sleeping.
2016-07-03 Added automatic interval picture code, working
    New version takes a picture automatically at the specified time
    interval, and retains the manual trigger option as well. Tested working
    on battery power, sleeping at <1mA between pictures.
2016-07-03 Adding Eagle PCB design files
    [Timelapse_camera_RevB.brd, Timelapse_camera_RevB.sch]
2016-07-03 Image of assembled Revision B circuit board
2016-07-03 Adding parts list
    [Timelapse_camera_RevB_parts.xlsx]
2016-07-04 Updating circuit board link
2016-07-04 Altered reboot LED signal to just use green
    Also using green led instead of red to indicate picture taking (at the
    delay)
    [Timelapse_arducam.ino]
2016-07-07 Adding successful bootup quick flash
    Green will flash on reboot, and if the camera and SD card both
    initialize then a 2nd faster green flash will occur before the main loop
    starts.
    [Timelapse_arducam.ino]
2016-07-09 Writing clean JPEG files now, after removing static int
    In the writeToSD function there was a variable declaration static int i
    = 0; This appears to have been preserving the i value between function
    calls (separate image-to-SD write events), and so adding some of the
    previous image's data to the start of the current image, making a
    semi-corrupted jpeg. Changing i to a standard int instead of static int
    appears to have fixed this.
    [Timelapse_arducam.ino]
2016-07-09 Setting reboot flashes, cleaning functions
    Adding comments and user guide in preamble. Cleaning up + formatting
    comments.
    [Timelapse_arducam.ino]
2016-07-22 Fixing all the stuff the merge broke
    [Timelapse_arducam.ino]
2016-07-22 Created a boards.txt entry for Arduino
2018-05-06 Moving Rev B to its own folder
    [Timelapse_camera_RevB.brd, Timelapse_camera_RevB.sch]
2018-05-06 Creating RevC with GPIO breakouts
    [Timelapse_camera_RevC.brd, Timelapse_camera_RevC.sch]

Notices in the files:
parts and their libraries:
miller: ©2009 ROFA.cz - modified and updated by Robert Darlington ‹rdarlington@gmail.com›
